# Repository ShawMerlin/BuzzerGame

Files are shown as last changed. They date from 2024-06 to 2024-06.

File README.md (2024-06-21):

# BuzzerGame

I modified the below Amazon Buzzers with my own 3 color LED board and Arduino Uno R3 Hat to run them. <br> <br>

The Buttons X LED's will be blue until someone hits one, the one hit will turn Green while the other will turn red <br>
They will stay in this state until the Clear Button is pressed. <br>
This also uses the buzzer from the original game to buzz when they are selected. <br>
Modification of the original button is needed. <br> <br>

https://www.amazon.com/gp/product/B07WJLD44G <br>


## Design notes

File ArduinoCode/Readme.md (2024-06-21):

Below is the code I used for the Arduino Uno R3 and Buzzer Game Hat. <br> <br>

```ruby
// Define the LED pins

const int sleepButton = 14; // #Sleep Button         A0
const int MuteButton = 15;  // #Mute Button          A1
const int RED1 = 16;        // ##Player 1 Red LED    A2
const int BLUE1 = 17;       // ##Player 1 Blue LED   A3
const int GREEN1 = 18;      // ##Player 1 Green LED  A4
const int buttonC = 19;     // ##Button C -          A5

const int BuzzerP2 = 9;     // #Player 2 Buzzer -    D9
const int BuzzerP1 = 8;     // #Player 1 Buzzer -    D8
const int buttonB = 7;      // #Button B -          D7
const int buttonA = 6;      // #Button A -          D6
const int ClearLED = 5;     // #Clear Button LED -   D5
const int RED2 = 4;         // #Player 1 Red LED    D4
const int BLUE2 = 3;        // #Player 1 Blue LED   D3
const int GREEN2 = 2;       // #Player 1 Green LED  D2

int WaitForClear = 0; // #Initialize the variable

// #Variables to store the previous state of each button
bool prevButtonAState = LOW;
bool prevButtonBState = LOW;
bool prevButtonCState = HIGH; // #Initial state is HIGH because of internal pull-up resistor
bool sleepButtonState = HIGH;
bool MuteButtonState = HIGH;

void setup() {
  // #Initialize each pin as an output
  // #Serial.begin(9600); // Start the Serial communication
  // #Serial.println("Game is Starting ");
  // #Serial.println("");

  pinMode(RED1, OUTPUT);
  pinMode(BLUE1, OUTPUT);
  pinMode(GREEN1, OUTPUT);
  pinMode(RED2, OUTPUT);
  pinMode(BLUE2, OUTPUT);
  pinMode(GREEN2, OUTPUT);
  pinMode(ClearLED, OUTPUT);

  // #Initialize the digital pins for buzzers as outputs
  pinMode(BuzzerP1, OUTPUT);
  pinMode(BuzzerP2, OUTPUT);

  // #Set initial states for buzzers
  digitalWrite(BuzzerP1, LOW);
  digitalWrite(BuzzerP2, LOW);

  // #Initialize the digital pins for buttons as inputs
  pinMode(buttonA, INPUT);         // #Button A with external pull-down resistor
  pinMode(buttonB, INPUT);         // #Button B with external pull-down resistor
  pinMode(buttonC, INPUT_PULLUP);  // #Button C with internal pull-up resistor
  pinMode(sleepButton, INPUT); // #Sleep button with internal pull-DOWN resistor
  pinMode(MuteButton, INPUT); // #Mute button with internal pull-DOWN resistor

  // #Turn on all LEDs
  ClearLEDs();
  delay(500);

  digitalWrite(GREEN1, HIGH);
  digitalWrite(GREEN2, HIGH);

  delay(250);
  digitalWrite(GREEN1, LOW);
  digitalWrite(GREEN2, LOW);
  digitalWrite(BLUE1, HIGH);
  digitalWrite(BLUE2, HIGH);

  delay(250);
  digitalWrite(BLUE1, LOW);
  digitalWrite(BLUE2, LOW);
  digitalWrite(RED1, HIGH);
  digitalWrite(RED2, HIGH);

  delay(250);

  digitalWrite(RED1, LOW);
  digitalWrite(RED2, LOW);
  digitalWrite(BLUE1, HIGH);
  digitalWrite(BLUE2, HIGH);
}

void loop() {
  delay(50);
  bool buttonAState = digitalRead(buttonA);
  bool buttonBState = digitalRead(buttonB);
  bool buttonCState = digitalRead(buttonC);
  bool sleepButtonState = digitalRead(sleepButton);
  bool MuteButtonState = digitalRead(MuteButton);
  
  //#Serial.println("");    
  //#Serial.print(MuteButtonState);

  if (buttonAState == HIGH && WaitForClear == 0) {
    Player1Wins(MuteButtonState);
    WaitForClear = 1;
  } 
  if (buttonBState == HIGH && WaitForClear == 0) {
    Player2Wins(MuteButtonState);
    WaitForClear = 1;
  }

  // #Check if the sleep button is pressed
  if (sleepButtonState == HIGH) {  //# Change to Low when using it in the box
    digitalWrite(ClearLED, LOW); 
    digitalWrite(BuzzerP1, LOW); 
    digitalWrite(BuzzerP2, LOW); 
    digitalWrite(ClearLED, LOW);
    ClearLEDs();
    while (digitalRead(sleepButton) == HIGH) {
      delay(50);    // #Wait until the sleep button is released
    }
    ClearLEDs();
    digitalWrite(BLUE1, HIGH);
    digitalWrite(BLUE2, HIGH);
    WaitForClear = 0;
  }

  if (buttonCState == LOW && WaitForClear == 1) {
    ClearLEDs();
    digitalWrite(BLUE1, HIGH);
    digitalWrite(BLUE2, HIGH);
    digitalWrite(ClearLED, LOW);
    WaitForClear = 0;
  }
}

void ClearLEDs() {
  digitalWrite(RED1, LOW);
  digitalWrite(RED2, LOW);
  digitalWrite(GREEN1, LOW);
  digitalWrite(GREEN2, LOW);
  digitalWrite(BLUE1, LOW);
  digitalWrite(BLUE2, LOW);
  digitalWrite(ClearLED, LOW);
  digitalWrite(BuzzerP1, LOW);
  digitalWrite(BuzzerP2, LOW);
}

void Player1Wins(bool MuteButtonState) {
  if (MuteButtonState == 1) { 
    digitalWrite(BuzzerP1, HIGH);
  }
  digitalWrite(BuzzerP2, LOW);
  digitalWrite(GREEN1, HIGH);
  digitalWrite(BLUE1, LOW);
  digitalWrite(RED1, LOW);
  digitalWrite(GREEN2, LOW);
  digitalWrite(BLUE2, LOW);
  digitalWrite(RED2, HIGH);
  digitalWrite(ClearLED, HIGH);
  delay(50);
  digitalWrite(BuzzerP1, LOW);
}

void Player2Wins(bool MuteButtonState) {
  if (MuteButtonState == 1) { 
    digitalWrite(BuzzerP2, HIGH);
  }
  digitalWrite(BuzzerP1, LOW);
  digitalWrite(GREEN2, HIGH);
  digitalWrite(BLUE2, LOW);
  digitalWrite(RED2, LOW);
  digitalWrite(GREEN1, LOW);
  digitalWrite(BLUE1, LOW);
  digitalWrite(RED1, HIGH);
  digitalWrite(ClearLED, HIGH);
  delay(50);
  digitalWrite(BuzzerP2, LOW);
}

```

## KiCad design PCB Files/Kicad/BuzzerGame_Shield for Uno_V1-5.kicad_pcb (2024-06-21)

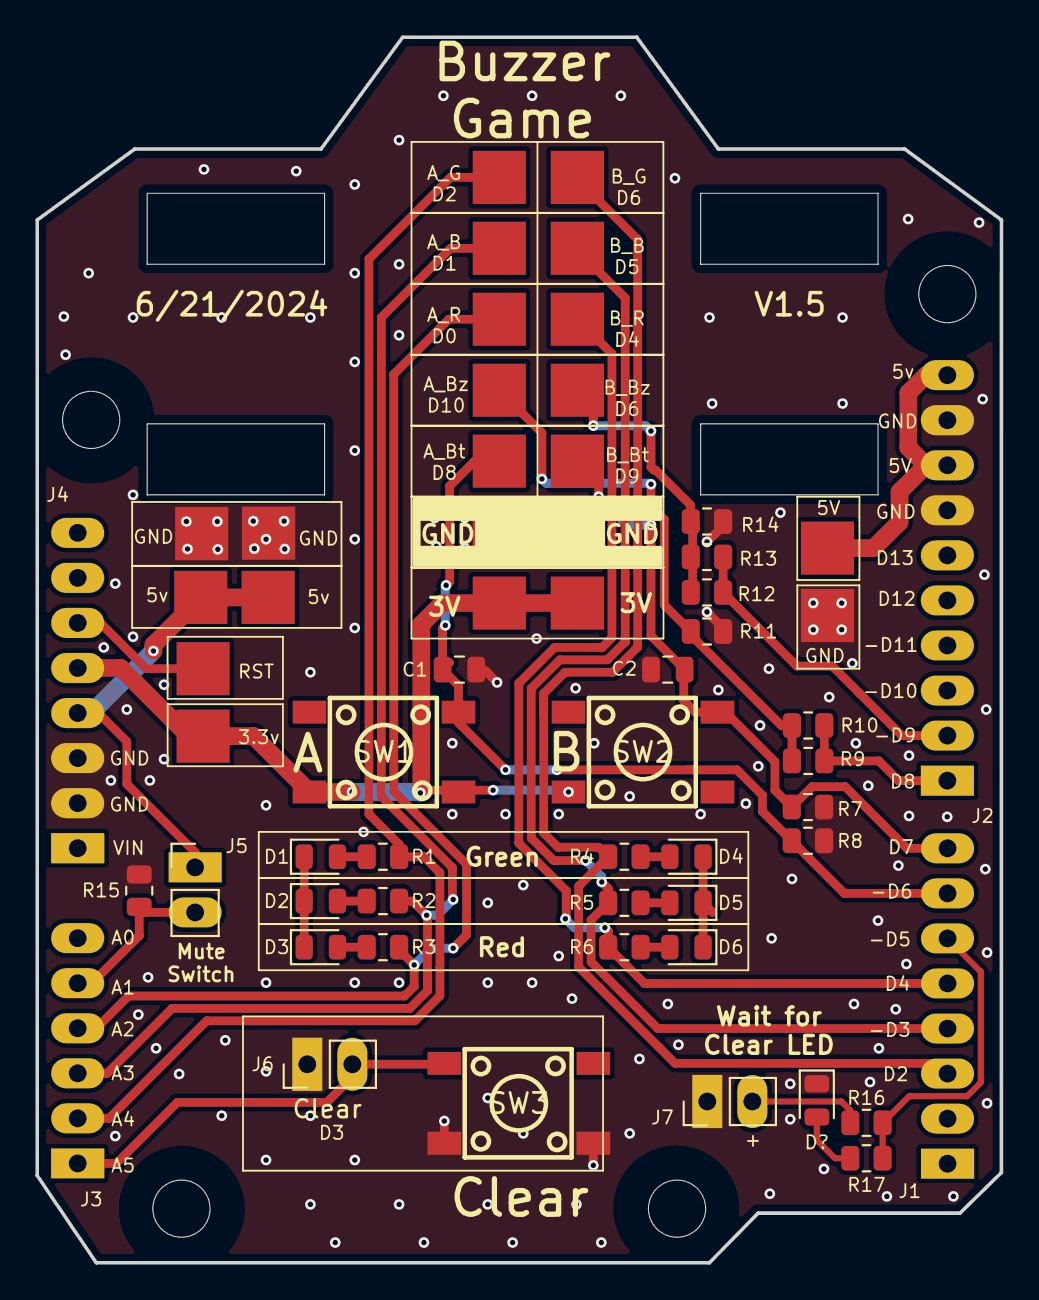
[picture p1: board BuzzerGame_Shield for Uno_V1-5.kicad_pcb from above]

Board: 2 copper layers, 54.4 x 69.1 mm, 46 parts (0 on the bottom side), 29 nets.

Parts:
C1, C2: 10K; C_0805_2012Metric
D1, D2, D3, D4, D5, D6: Green; LED_0805_2012Metric
D?: White; LED_0805_2012Metric
GND: PinHeader_1x07_P2.54mm_Vertical
GND#2, GND#3: PinHeader_1x07_P2.54mm_Vertical
J1, J1#2, J1#3, J1#5, J1#6, J1#7, J1#8: PinHeader_1x07_P2.54mm_Vertical
J1#4, J4: PinHeader_1x08_P2.54mm_Vertical
J2: PinHeader_1x10_P2.54mm_Vertical
J3: PinHeader_1x06_P2.54mm_Vertical
J5, J6, J7: PinHeader_1x02_P2.54mm_Vertical
R1, R2, R3, R6, R8: 2K; R_0805_2012Metric
R4, R5, R15, R16, R17: 10R; R_0805_2012Metric
R7, R9, R10, R11, R12, R13, R14: 10K; R_0805_2012Metric
SW1, SW2, SW3: KEY-SMD_4P-L6.0-W6.0-P4.50-LS9.0

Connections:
3v: J1#2.3V, J1#3.1, J1#8.1, J4.5, SW1.3, SW1.4, SW2.3
5V: J1#5.5V, J1#6.5V, J1#7.5V, J2.8, J2.10, J4.4, J5.1
ABLUE: J1#8.6, J3.3, R2.2
AGREEN: J1#8.7, J3.2, R1.2
ARED: J1#8.5, J3.4, R3.2
A_Button: C1.2, J1#4.7, J1#8.3, R8.2, SW1.2
A_Buzz_Out: J1#8.4, R9.2, R10.2, R11.2
A_Buzzer: J2.1, R9.1, R10.1
BBLUE: J1#3.6, J1#4.4, R5.2
BGREEN: J1#3.7, J1#4.3, R4.2
BRED: J1#3.5, J1#4.5, R6.2
B_Button1: C2.1, J1#3.3, J1#4.8, R7.2, SW2.2
B_Buzz_Out: J1#3.4, R12.2, R13.2, R14.2
B_Buzzer: J2.2, R12.1, R13.1
Clear1: J3.1, J6.2, SW3.1
GND: C1.1, C2.2, D?.1, GND.GBD, GND#2.GBD, GND#3.GBD, J1#3.2, J1#8.2, J2.7, J2.9, J4.2, J4.3, J6.1, J7.1, R7.1, R8.1, R11.1, R14.1, R15.1, SW3.3, SW3.4
ICC1: D1.2, R1.1
ICC2: D2.2, R2.1
ICC3: D3.2, R3.1
ICC4: D4.2, R4.1
ICC5: D5.2, R5.1
ICC6: D6.2, R6.1
ICC9: D?.2, R17.1
LEDGND: D1.1, D2.1, D3.1
LEDGND1: D4.1, D5.1, D6.1
Mute: J3.5, J5.2, R15.2
RST: J1.RST, J4.6
WFC: J7.2, R16.1
WaitforClear: J1#4.6, R16.2, R17.2
